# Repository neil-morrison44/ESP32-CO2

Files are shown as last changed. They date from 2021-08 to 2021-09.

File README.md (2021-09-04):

# ESP32-CO2
CO2 + TVOC + Humidity monitor using the ESP32

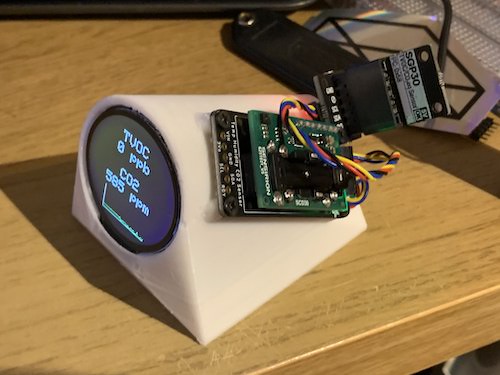
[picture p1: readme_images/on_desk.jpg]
Image of the device on a desk


## BOM
  - 1x ESP32 (Adafruit Feather HUZZAH32)
  - 1x Round 1.28" LCD Display Module (Waveshare)
  - 1x SCD-30 (Adafruit)
  - 1x SGP30 (pimoroni)
  - Some white PLA+
  - Some screws
  - Wires & Cables
  - A Qwiic to Breakout Garden converter
  - A Qwiic to dupoint converter

## Building Notes
  - Print the 3D models, printer settings don't really matter
  - Attach the ESP32 to the base plate using screws
  - Need to shorten the wires for the display, can seperate them out into 3x 3pin dupoint connnectors for SPI, 3v+gap+Ground, the backlight+reset+dc(?) pin as well
  - Can plug the Qwiic to dupoint converter in & pass it through the big hole in the case
  - Close the case, connect the display cables to the board using tweezers through the hole
  - Connect the SCD30 to the Qwiic line from the board
  - Connect the SGP30 using a Qwiic line from the SCD30
  - Screw down the sensors
  - Follow the Homespan guide for setting up WiFi & pairing (everything was just left as default)

## Notes
  - Uses [Homespan](https://github.com/HomeSpan/HomeSpan) so it really connects to HomeKit instead of via Homebridge
  - I wanted to also store a CSV of the readings within the ESP32's filesystem but I'd probably never read it.
  - For some reason the temperature readings are considerably off for the first minute or so of plugging the device in

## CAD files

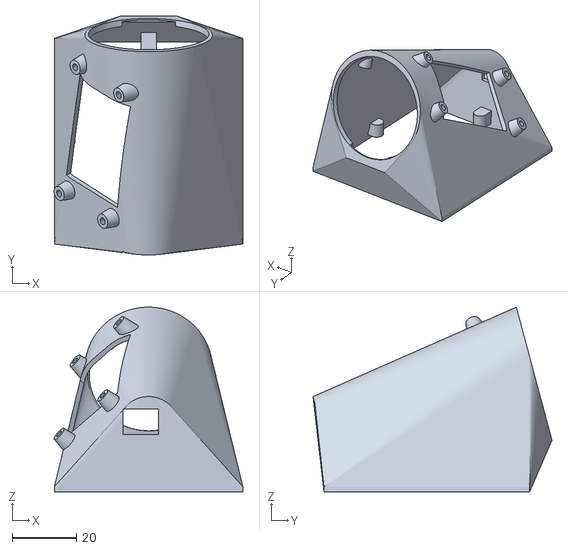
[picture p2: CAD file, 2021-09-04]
3dmodels/top.stl
58.7 x 74.3 x 57.4

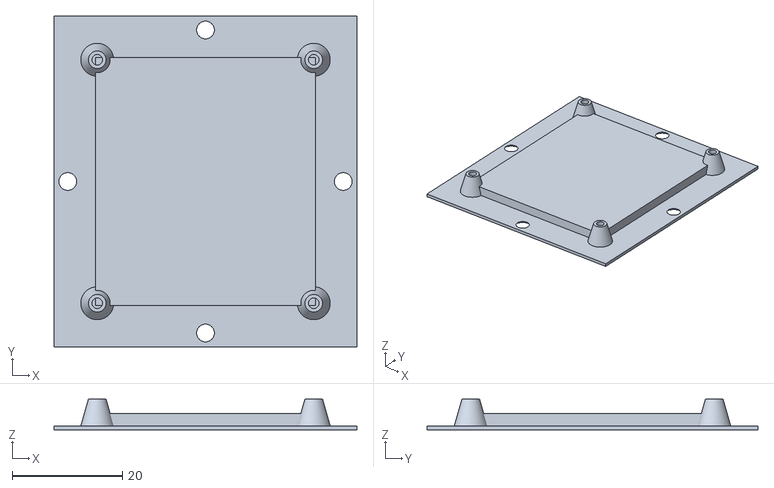
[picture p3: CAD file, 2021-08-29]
3dmodels/base.stl
55.0 x 60.0 x 5.60

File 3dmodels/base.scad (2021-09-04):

$fa = 0.1;
$fs = 0.1;
$boardDepth = 50;
$boardWidth = 45;
$boardHeight = 2.6;

$holeRadius = 3.2 / 2;
$screwRadius = 1.92 / 2;

$topScrewRadius = 2.75 / 2;

$screwDepth = 44.2;
$screwWidth = 39.3;

$lip = 5;

$baseDepth = $boardDepth + $lip;
$baseWidth = $boardWidth + $lip;
$baseHeight = 3;

$lipHeight = $baseHeight / 4;

$counterSinkHeight = 2;

module baseBoard() {
  cube([ $boardWidth - 5, $boardDepth - 5, $baseHeight ], true);

  translate([ 0, 0, (-($baseHeight / 2)) + ($lipHeight) / 2 ])
      cube([ $baseWidth + $lip, $baseDepth + $lip, $lipHeight ], true);
}

module boardScrewHoles() {
  for (x = [ -($screwWidth / 2), ($screwWidth / 2) ]) {
    for (y = [ -($screwDepth / 2), ($screwDepth / 2) ]) {
      translate([ x, y, -($baseHeight / 2) ]) difference() {
        cylinder($boardHeight + $baseHeight, $holeRadius * 2, $holeRadius);
        translate([ 0, 0, 0.1 ]) cylinder($boardHeight + $baseHeight, $screwRadius, $screwRadius);
      }
    }
  }
}

module topScrewHoles() {
  for (x = [ -($baseWidth / 2), 0, ($baseWidth / 2) ]) {
    for (y = [ -($baseDepth / 2), 0, ($baseDepth / 2) ]) {
      if ((x == 0 || y == 0) && (x != y)) {
        translate([ x, y, -($baseHeight / 2 + 0.1) ]) cylinder($lipHeight + 0.2, $topScrewRadius + 1, $topScrewRadius);
      }
    }
  }
}

module baseScrewHoles(height = 10) {
  translate([ 0, 0, $lipHeight ]) {
    for (x = [ -($baseWidth / 2), 0, ($baseWidth / 2) ]) {
      for (y = [ -($baseDepth / 2), 0, ($baseDepth / 2) ]) {
        if ((x == 0 || y == 0) && (x != y)) {
          translate([ x, y, -($baseHeight / 2 + 0.1) ]) difference() {
            hull() {
              cylinder(height, $topScrewRadius + 1, $topScrewRadius + 1);
              translate([ x / 5, y / 2, 0 ]) { cylinder(height, $topScrewRadius + 1, $topScrewRadius + 1); }
            }
            translate([ 0, 0, -0.1 ]) cylinder(height, $topScrewRadius, $topScrewRadius);
          }
        }
      }
    }
  }
}

module wholeBase() {
  difference() {
    baseBoard();
    topScrewHoles();
  }
  boardScrewHoles();
}

wholeBase();
% baseScrewHoles();

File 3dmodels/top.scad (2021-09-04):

use <base.scad>
$fa = 0.5;
$fs = 0.5;
//$screenRadius = 35.5 / 2;
$screenRadius = 37.8 / 2;
$usbHeight = 16 + 2.6;

$tubeHeight = 65;

$tubeAngle = -75;

$sensorScrewLength = 45.6;
$sensorScrewWidth = 20;

$actualSensorLength = 36.5;
$actualSensorWidth = 23.5;

$sensorScrewRadius = 2.3 / 2;
$screenScrewRadius = 2.3 / 2;

$screenScrewWidth = 26.5;
$screenDepth = 6.1;

$chinDepth = 4;
$chinWidth = 16.6;
$chinHeight = 6;

module outerShape(floorOffset = 0, screenHole = false) {
  hull() {
    translate([ 0, 0, -floorOffset ]) scale([ 1.005, 1.005, 2 ]) { scale([ 1.01, 1.01, 1.01 ]) baseBoard(); }
    translate([ 0, 0, 25 ]) rotate([ $tubeAngle, 0, 0 ]) innerTube();
  }

  if (screenHole) {
    translate([ 0, 0, 25 ]) rotate([ $tubeAngle, 0, 0 ]) translate([ 0, 0, 2.5 ]) innerTube(1, 1);
  }
}

module innerTube(heightOffset = 0, chinOffset = 0) {
  union() {
    cylinder($tubeHeight + heightOffset, $screenRadius - 10, $screenRadius, true);
    translate([ 0, $screenRadius, ($tubeHeight / 2) - ($chinDepth / 2) - chinOffset ])
        cube([ $chinWidth, $chinHeight, $chinDepth ], true);
  }
}

module usbHole() { translate([ -2.5, -20, $usbHeight ]) cube([ 11, 50, 8 ], true); }

module sensorPosition() { translate([ -16, 0, 30 ]) rotate([ 12, -50, 5 ]) rotate([ 0, 0, -30 ]) children(); }

module sensorScrews() {
  sensorPosition() {
    for (x = [ -($sensorScrewWidth / 2), ($sensorScrewWidth / 2) ]) {
      for (y = [ -($sensorScrewLength / 2), ($sensorScrewLength / 2) ]) {
        translate([ x, y, 0 ]) difference() {
          cylinder(7, $sensorScrewRadius * 3, $sensorScrewRadius * 2, true);
          translate([ 0, 0, 0.1 ]) cylinder(7, $sensorScrewRadius, $sensorScrewRadius, true);
        }
      }
    }
  }
}

module sensorHole() {
  sensorPosition() { cube([ $actualSensorWidth, $actualSensorLength, 10 ], true); }
}

module screenScrews() {
  translate([ 0, 22, 43 ]) {
    for (x = [ -($screenScrewWidth / 2), ($screenScrewWidth / 2) ]) {
      translate([ x, 0, 0 ]) {
        rotate([ 90 + $tubeAngle, 0, 0 ]) {
          difference() {
            union() {
              translate([ 0, 0, 3 / 2 ]) sphere($screenScrewRadius * 2);
              cylinder(3, $screenScrewRadius * 2, $screenScrewRadius * 2, true);
            }

            translate([ 0, 0, -0.1 ]) cylinder(10, $screenScrewRadius, $screenScrewRadius, true);
          }
        }
      }
    }
  }
}

difference() {
  scale([ 1.05, 1.05, 1.05 ]) outerShape();
  outerShape(1, true);
  usbHole();
  sensorHole();
}

scale([ 1.01, 1.01, 1.01 ]) intersection() {
  baseScrewHoles(5);
  outerShape();
}

difference() {
  sensorScrews();
  outerShape();
}

intersection() {
  screenScrews();
  outerShape();
}

% wholeBase();

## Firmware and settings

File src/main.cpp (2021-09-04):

#include <Adafruit_SCD30.h>
#include <Arduino_GFX_Library.h>
#include <math.h>
#include <Adafruit_SGP30.h>
#include "./homekit.h"
#include "./aqi.h"
#include "./graph.h"

Adafruit_SGP30 sgp;
Adafruit_SCD30 scd30;
Arduino_DataBus *bus = new Arduino_HWSPI(15 /* DC */, 4 /* CS */);
Arduino_GFX *gfx = new Arduino_GC9A01(bus, TFT_RST, 0 /* rotation */, false /* IPS */);

// const int CO2ValueCount = 50;
const int CO2ValueCount = 240;
float CO2Values[CO2ValueCount];
int readingPosition = 0;

float lastCO2Reading = 400.0;
int lastTVOCReading = 0;
int lastIAQValue = 0;
float lastHumidityReading = 0;

bool loopSerialOutput = false;

#define CO2_WARNING_LEVEL 1250

void addNewCO2Reading(float reading)
{
  if (readingPosition < CO2ValueCount)
  {
    CO2Values[readingPosition] = reading;
    readingPosition++;
  }
  else
  {
    for (int i = 0; i < CO2ValueCount - 1; i++)
    {
      CO2Values[i] = CO2Values[i + 1];
    }
    CO2Values[CO2ValueCount - 1] = reading;
  }
}

uint32_t getAbsoluteHumidity(float temperature, float humidity)
{
  // approximation formula from Sensirion SGP30 Driver Integration chapter 3.15
  const float absoluteHumidity = 216.7f * ((humidity / 100.0f) * 6.112f * exp((17.62f * temperature) / (243.12f + temperature)) / (273.15f + temperature)); // [g/m^3]
  const uint32_t absoluteHumidityScaled = static_cast<uint32_t>(1000.0f * absoluteHumidity);                                                                // [mg/m^3]
  return absoluteHumidityScaled;
}

void setup(void)
{
  Serial.begin(115200);
  while (!Serial)
    delay(10); // will pause Zero, Leonardo, etc until serial console opens

  gfx->begin();
  gfx->fillScreen(BLACK);

#ifdef TFT_BL
  pinMode(TFT_BL, OUTPUT);
  digitalWrite(TFT_BL, HIGH);
#endif
  gfx->invertDisplay(true);
  Serial.println("Adafruit SCD30 Sensor adjustment test!");

  // Try to initialize!
  if (!scd30.begin())
  {
    gfx->setCursor(0, 120 - 6);
    gfx->setTextColor(RED);
    gfx->println("Failed to find SCD30 chip");
    Serial.println("Failed to find SCD30 chip");
    while (1)
    {
      delay(10);
    }
  }
  Serial.println("SCD30 Found!");

  if (!scd30.setTemperatureOffset(400))
  {
    Serial.println("Failed to set temperature offset");
    while (1)
    {
      delay(10);
    }
  }

  if (!sgp.begin())
  {
    gfx->setCursor(0, 120 - 6);
    gfx->setTextColor(RED);
    gfx->println("Failed to find SGP30 chip");
    Serial.println("Failed to find SGP30 chip");
    while (1)
    {
      delay(10);
    }
  }
  Serial.println("SGP30 Found!");

  setupHomeKit(&lastCO2Reading, &lastTVOCReading, &lastIAQValue, &lastHumidityReading);
}

void loop()
{
  loopHomeKit();

  if (scd30.dataReady())
  {

    if (!scd30.read())
    {
      Serial.println("SCD30: Error reading sensor data");
      return;
    }

    sgp.setHumidity(getAbsoluteHumidity(scd30.temperature, scd30.relative_humidity));

    if (!sgp.IAQmeasure())
    {
      Serial.println("SGP30: Measurement failed");
      return;
    }

    if (loopSerialOutput)
    {

      Serial.print("TVOC ");
      Serial.print(sgp.TVOC);
      Serial.print(" ppb\t");
      Serial.print("eCO2 ");
      Serial.print(sgp.eCO2);
      Serial.println(" ppm");

      if (!sgp.IAQmeasureRaw())
      {
        Serial.println("Raw Measurement failed");
        return;
      }
      Serial.print("Raw H2 ");
      Serial.print(sgp.rawH2);
      Serial.print(" \t");
      Serial.print("Raw Ethanol ");
      Serial.print(sgp.rawEthanol);
      Serial.println("");

      Serial.print("Temperature: ");
      Serial.print(scd30.temperature);
      Serial.println(" degrees C");

      Serial.print("Relative Humidity: ");
      Serial.print(scd30.relative_humidity);
      Serial.println(" %");

      Serial.print("CO2: ");
      Serial.print(scd30.CO2, 3);
      Serial.println(" ppm");
      Serial.println("");

      Serial.print("Temperature offset: ");
      Serial.print((float)scd30.getTemperatureOffset() / 100.0);
      Serial.println(" degrees C");

      printf("\nIAQ: %d \n ", calculateAQI(scd30.CO2, sgp.TVOC, scd30.relative_humidity, scd30.temperature));
    }

    lastCO2Reading = scd30.CO2;
    lastTVOCReading = sgp.TVOC;
    lastHumidityReading = scd30.relative_humidity;
    lastIAQValue = calculateAQI(scd30.CO2, sgp.TVOC, scd30.relative_humidity, scd30.temperature);

    String co2Text = String(String(lastCO2Reading, 0) + " ppm");
    String TVOCText = String(String(lastTVOCReading) + " ppb");

    addNewCO2Reading(lastCO2Reading);
    gfx->setTextSize(3);
    gfx->setTextColor(WHITE);
    gfx->fillScreen(BLACK);

    gfx->setCursor((120 - ((4 * 18) / 2)), 30);
    gfx->println("TVOC");
    gfx->setCursor((120 - ((TVOCText.length() * 18) / 2)), 30 + 28);

    if (lastTVOCReading > 500)
    {
      gfx->setTextColor(RED);
    }
    else if (lastTVOCReading > 250)
    {
      gfx->setTextColor(YELLOW);
    }

    gfx->println(TVOCText);

    gfx->setTextColor(WHITE);

    gfx->setCursor((120 - ((3 * 18) / 2)), (120 - 14));
    gfx->println("CO2");
    if (lastCO2Reading > 2000)
    {
      gfx->setTextColor(RED);
    }
    else if (lastCO2Reading > 1000)
    {
      gfx->setTextColor(YELLOW);
    }

    gfx->setCursor((120 - ((co2Text.length() * 18) / 2)), (120 + 14));
    gfx->println(co2Text);

    //graph

    renderGraph(120, 190, 120, 50, gfx, CO2ValueCount, CO2Values);
  }

  delay(100);
}

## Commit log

2021-08-21 display stuff on the screen & start putting together the case
    [base.scad, top.scad]
2021-08-29 first "finishable" version of the case
    [base.scad, base.stl, top.scad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]
2021-09-04 Add TVOC sensor
    [base.scad, top.scad, top.stl]
2021-09-04 Add AQI calculations & TVOC / Humdity sensors
